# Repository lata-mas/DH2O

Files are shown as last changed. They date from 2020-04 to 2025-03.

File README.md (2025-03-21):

# Dispositivo H2O

Este dispositivo se realizó gracias al apoyo del proyecto UNAM-PAPIIT IT103023.

Este dispositivo se desarrollo con el objetivo de medir la cantidad de agua que se consume en un edificio y poder implementar medidas para evitar consumos excesivos de este valioso recurso.

El dispositivo funciona con un módulo NodeMCU Lolin V3→ESP8266-12E, permitiendo interpretar los datos que recolecta el sensor YF-S201 (sensor de caudal de agua), el microcontrolador  permite interpretar datos y después enviarlos a través de Wifi a una plataforma de imternet. La ventaja más significativa es precisamente esa, que el módulo tiene wifi, permitiendo que pueda enviar datos en tiempo real a diferentes plataformas de visualización, ademas de su reducido tamaño.

A continuación se muestra el esquema general del dispositivo y algunos de sus componetes principales:

1. Sensor de caudal
2. Divisor de voltaje
3. LM324

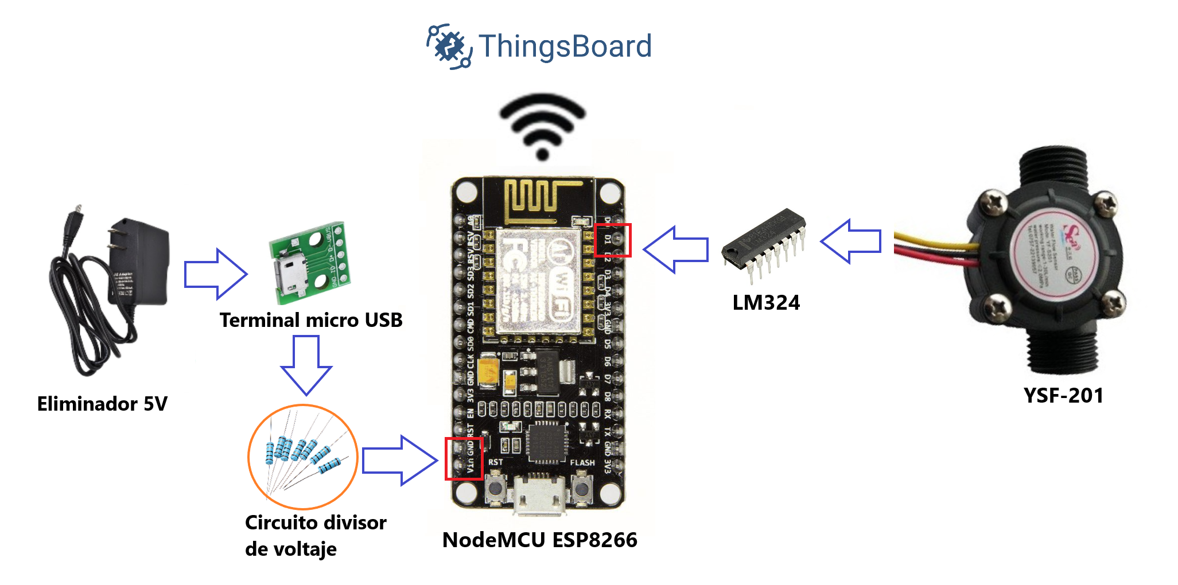
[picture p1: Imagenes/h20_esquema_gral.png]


[Diagrama electrico](https://github.com/Dispositivos-Edificio-Bioclimatico/DH2O/blob/master/Diagramas/DispositivoH2O1Esquem%C3%A1tico.pdf)

## 1. Elementos del repositorio
-  #### En [**docs**](https://github.com/Dispositivos-Edificio-Bioclimatico/DH2O/tree/master/Documentacion) encontramos
	-  Lista de materiales y costos
	-  Manual de operación
	-  Fichas técnicas o datasheet de los módulos, sensores y componentes usados
	- Documento de errores, soluciones y recomendaciones

-  #### En [**diagramas**](https://github.com/Dispositivos-Edificio-Bioclimatico/DH2O/tree/master/Diagramas) encontramos
	- Pictograma de conexión
	- Esquemático de conexión
	
-  #### En [**codigo**](https://github.com/Dispositivos-Edificio-Bioclimatico/DH2O/tree/master/codigo) encontramos
	- Códigos completos
	- Librerías a usar.
	- Explicación.

-  #### En [**Imagenes**](https://github.com/Dispositivos-Edificio-Bioclimatico/Sistema_medicion_apertura_ventanas/tree/main/notebook) encontramos
	-  Imagenes usadas en el repositorio

-  #### En [**carcasa**](https://github.com/Dispositivos-Edificio-Bioclimatico/DH2O/tree/master/Diagramas) encontramos
	-  Planos CAD
	-  Archivos de diseño CAD
	-  Archivos STL para impresión 3D

### 2 Sobre los autores

|Nombre|Instituto/Organización|Email|
| --- | --- | --- |
|Luis Fernando De Olarte Delgado|UTEZ|ferdeod16@gmail.com|
|Marco Antonio Morales Lagunes|UTEZ|marcostony001@gmail.com|
|Julio César Landa López|UTEZ|landajulioc@gmail.com|
|Miguel Ángel Gaspar|ITZ|miguel97gaz@gmail.com|
|Escobar Escobar José Williams|ITE|escobarescobarwilliams@gmail.com|
|Guillermo Barrios del Valle|IER-UNAM|gbv@ier.unam.mx|
|Guillermo Ramírez Zúñiga|IER-UNAM|guraz@ier.unam.mx|
|Giovanni Velazquez Avilez||velazquezgio96@gmail.com|
|José Diego Salgado Nieto||salgadojosediego@gmail.com|

------------

# 3 Alcance

El dispositivo H2O tiene como alcance, en esta etapa, contar con toda la documentación necesaria para ser replicado de manera eficaz y eficientemente, después de ser trabajado por un grupo de personas se espera que el proyecto tenga todo lo que se necesita para que otras personas puedan entender el funcionamiento y requisitos de operación.

------------

### 4 Contacto primario

**Inv. A tiempo completo:** Dr. Guillermo Barrios del Valle

**Email:** gbv@ier.unam.mx

**Posdoc.:** Dr. Guillermo Ramírez Zúñiga

**Email:** guraz@ier.unam.mx

### Colaboradores

**Nombre:** Luis Fernando De Olarte Delgado

**Instituto:** Universidad Tecnológica Emiliano Zapata (UTEZ)

**Email:** ferdeod16@gmail.com

**Nombre:** Marco Antonio Morales Lagunes

**Instituto:** Universidad Tecnológica Emiliano Zapata (UTEZ)

**Email:** marcostony001@gmail.com

**Nombre:** Julio César Landa López

**Instituto:** Universidad Tecnológica Emiliano Zapata (UTEZ)

**Email:** landajulioc@gmail.com

**Nombre:** Miguel Ángel Gaspar

**Instituto:** Instituto Tecnológico de Zacatepec (ITZ)

**Email:** miguel97gaz@gmail.com

**Nombre:** Escobar Escobar José Williams

**Instituto:** Instituto Tecnológico de Ensenada (ITE)

**Email:** escobarescobarwilliams@gmail.com

**Nombre:** Salgado Nieto josé Diego
**Insituto** Universidad Tecnológica Emiliano Zapata (UTEZ)
**Email:** salgadojosediego@gmail.com

#### 5 Seguimiento de actividades del dispositivo H2O

|**Actividad**|**Tiempo estimado de ejecución**|**Referenciación**|
| :---: | :---: | :---: |
|**1. Revisión de documentos existentes necesarios para operarlo de acuerdo a la CHECK-LIST**|2 h|[**°Documentación**](https://github.com/Dispositivos-Edificio-Bioclimatico/SensorH2O/tree/master/Documentacion) |
| | | |
|**2. Verificar si cuenta con los materiales requeridos**|1/2 h|[**Materiales**](https://github.com/Dispositivos-Edificio-Bioclimatico/DH2O/tree/master/Documentacion/Materiales)|
| | | |
|**3. Imprimir la carcasa en 3D (3 PARTES)**|16 h|[**Archivos STL**](https://github.com/Dispositivos-Edificio-Bioclimatico/DH2O/tree/master/carcasa)|
| | | |
|**4. Leer el manual de operación para entender lo que se hará**|1 h|[**Manual**](https://github.com/Dispositivos-Edificio-Bioclimatico/DH2O/blob/master/Documentacion/Manuales/ManualDeOperacion.md)|
| | | |
|**5. Entender los diagramas de conexión**|1/2 h|[**Diagramas**](https://github.com/Dispositivos-Edificio-Bioclimatico/DH2O/blob/master/Diagramas/H2O-Esquem%C3%A1tico_2023ver2-KiCad.pdf)|
| | | |
|**6. Descargar e instalar el código completo (son 5 .py)**|1/2 h|[**Código H2O**](https://github.com/Dispositivos-Edificio-Bioclimatico/DH2O/tree/master/codigo)|
| | | |
|**7. Ejecutar el código como primera prueba y asegurarse que funciona**| | |
| | | |
|**8. Montar el dispositivo en el lugar requerido**|1 h| |
| | | |
|**9. Dejarlo operando durante 24 horas como prueba "Burn it"**|24 h| |
| | | |
|**10. Tiempo total apróximado:**|**3 días**|Dependerá de la habilidad y conocimientos que se tengan, puede llevar menos tiempo o más|

------------

### Thingsboard

Dashboard del dispositivo H2O en la plataforma de Thingsboard:

Miguel_H2O

Las credenciales para tener acceso se deberán solicitar con alguno de los doctores.

La web (Dashboard) se encuentra aquí:

[**Miguel_H2O**](http://iot.ier.unam.mx:8080/dashboard/5825dc60-059e-11eb-9c3f-d1ead9980bc3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)

------------

# 6 Bibliografía

[1] Open Know-How
https://app.standardsrepo.com/MakerNetAlliance/OpenKnowHow/src/branch/master/1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

[2] Github
https://github.com/

[3] EasyEDA
https://easyeda.com/editor

[4] Fritzing
https://fritzing.org/

[5] DILLINGER
https://dillinger.io/

[6] M Editor.md
https://pandao.github.io/editor.md/en.html

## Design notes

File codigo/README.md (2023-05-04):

# SensorH2O
Repositorio para el proyecto de los sensores de flujo de agua para el nuevo edificio del IER-UNAM.

Esta versión del proyecto se conforma de un código modular para facilitar la manipulación de ciertos parámetros que nos ayuden a monitorear el flujo de agua en una tubería o si se requiere hasta 8 tuberías.

En este repositorio se encuentran los codigos requeriods parael funcionamiento del dispositivo.
El mismo se conforma por:

- main.py
- wifi.py
- funciones.py
- funcion.py

A continuación se explicara brevemente el funcionamiento de cada modulo

#### main.py

Este es el principal script de dispositivo y se ejcuta inmediatamente el ESP es alimentado.

Se encarga de declarar las variables las variables necesarias para activar al sensor por medio del llamado a funciones.py
entra en un bucle while y realiza las mediciones, espera 10 segundos a una nueva acción y publica el resultado en Thinsboard.

## funciones.py

**Clase conteo**

Esta clase crea un objeto, este objeto será el sensor que se utilizará para la medición del flujo de agua.

La clase se compone de seis métodos. 

**Método init**

El método **init** no es más que para definir la varibale contador y la variable de entrada pin.

**Método callback**

El método **callback** es el que sirve para aumentar en 1 la variable contador cada señal recibida.

**Método irq**

El método **irq** es el que detecta cada pulso digital y envía la señal al metodo callback.

**Método ecuaciones**

Este método es el que aplica las constantes de conversión al conteo de pulsos digitales para así obtener una variable en Litros.

**Método datos**

Este método tan solo sirve para empaquetar los datos junto con una etiqueta para que estén listos.
para ser publicados en Thingsboard.	

**Método publica**

Este metodo se encarga de verificar si hay algún consumo de agua, de serlo así almacena los datos, en cuanto detecta que ya no lo hay, comineza un conteo, el conteo se interrumpe si vuelve a haber consumo, si el conteo concluye, publica los datos en Thingsboard.

#### wifi.py y funcion.py
Esots archivos son los encargados de realizar la conexión a internet y al servidor de Thingsboard del IER-UNAM

**Última actualización de códigos por José Diego**

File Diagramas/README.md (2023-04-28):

##Diargramas del DH2O

En esta carpeta se presentan los diagramas.

Todo aquel documento qque represente como se construyó el dispositivo, diagramas de conexión, diagramas esequematicos y documentos CAD para su carcasa.
Los diagramas fueron realizados con el software libre KIcad, las carpetas presentan versiones de esquematicos y de pbc que muestran distintas formas de alimentación. Ambas versiones son funcionales, queda a elección del usuario cual usar.

En los directorios es posible encontrr los archivos gerber correspondientes para su  fabricación en PCB.

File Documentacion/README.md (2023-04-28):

## Documentación DH2O

#### En este repositorio es posible encontrar las docuemntación referenten a:

* Lista de materiales y costos
* Manuales de funcionamiento
* Calibración y configuración
* Pendientes identificados
* Recomendaciones

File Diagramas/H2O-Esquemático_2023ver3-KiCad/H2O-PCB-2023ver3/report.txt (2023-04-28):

Plotted to 'C:\Users\bol_j\Desktop\Estadias\DH2O_2\diagramas_ver2023\H2O-Esquemático_2023ver3-KiCad\H2O-PCB-2023ver3\H2O-Esquemático_2023ver3-KiCad-F_Cu.gbr'.
Plotted to 'C:\Users\bol_j\Desktop\Estadias\DH2O_2\diagramas_ver2023\H2O-Esquemático_2023ver3-KiCad\H2O-PCB-2023ver3\H2O-Esquemático_2023ver3-KiCad-B_Cu.gbr'.
Plotted to 'C:\Users\bol_j\Desktop\Estadias\DH2O_2\diagramas_ver2023\H2O-Esquemático_2023ver3-KiCad\H2O-PCB-2023ver3\H2O-Esquemático_2023ver3-KiCad-F_Paste.gbr'.
Plotted to 'C:\Users\bol_j\Desktop\Estadias\DH2O_2\diagramas_ver2023\H2O-Esquemático_2023ver3-KiCad\H2O-PCB-2023ver3\H2O-Esquemático_2023ver3-KiCad-B_Paste.gbr'.
Plotted to 'C:\Users\bol_j\Desktop\Estadias\DH2O_2\diagramas_ver2023\H2O-Esquemático_2023ver3-KiCad\H2O-PCB-2023ver3\H2O-Esquemático_2023ver3-KiCad-F_Silkscreen.gbr'.
Plotted to 'C:\Users\bol_j\Desktop\Estadias\DH2O_2\diagramas_ver2023\H2O-Esquemático_2023ver3-KiCad\H2O-PCB-2023ver3\H2O-Esquemático_2023ver3-KiCad-B_Silkscreen.gbr'.
Plotted to 'C:\Users\bol_j\Desktop\Estadias\DH2O_2\diagramas_ver2023\H2O-Esquemático_2023ver3-KiCad\H2O-PCB-2023ver3\H2O-Esquemático_2023ver3-KiCad-F_Mask.gbr'.
Plotted to 'C:\Users\bol_j\Desktop\Estadias\DH2O_2\diagramas_ver2023\H2O-Esquemático_2023ver3-KiCad\H2O-PCB-2023ver3\H2O-Esquemático_2023ver3-KiCad-B_Mask.gbr'.
Plotted to 'C:\Users\bol_j\Desktop\Estadias\DH2O_2\diagramas_ver2023\H2O-Esquemático_2023ver3-KiCad\H2O-PCB-2023ver3\H2O-Esquemático_2023ver3-KiCad-Edge_Cuts.gbr'.
Archivo de trabajo Gerber 'C:\Users\bol_j\Desktop\Estadias\DH2O_2\diagramas_ver2023\H2O-Esquemático_2023ver3-KiCad\H2O-PCB-2023ver3\H2O-Esquemático_2023ver3-KiCad-job.gbrjob' creado.
Info: Listo.

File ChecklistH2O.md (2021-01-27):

# CHECKLIST H2O
|Archivo/doc|Pendientes |Observación1|Observación2|Status |
| --- | --- | --- | --- | --- |
|Lista de costos|0|Unitario y total| |Listo|
|SRC completos|0| |Lo de Miguel|Listo|
|Pictogramas|0|De 1,2 y 8 sensores| |Listo|
|Esquemático|0| |1 y 8 sensores EasyEDA|Listo|
|Diseño PCB|0| |8 sensores EasyEDA|Listo|
|Gerber PCB|0|De 8 sensores| |Listo|
|Lista materiales|0|De 1 y 8 sensores| |Listo|
|Planos CAD|0|Planos en PDF| |Falta|
|CAD|1|En SolidWORKS|Falta FreCAD|Listo|
|STL|0| | |Listo|
|Manual Operación|0| | |Listo|
|Manual Ensamble|0| | |Listo|
|Fichas Técnicas|0| | |Listo|
|Doc. Errores y soluciones|0| | |Listo|

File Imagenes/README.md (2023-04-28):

## Imagenes

En este repositirio se encuentran alojadas todas las imagenes que se usan en el repositirio del DH2O

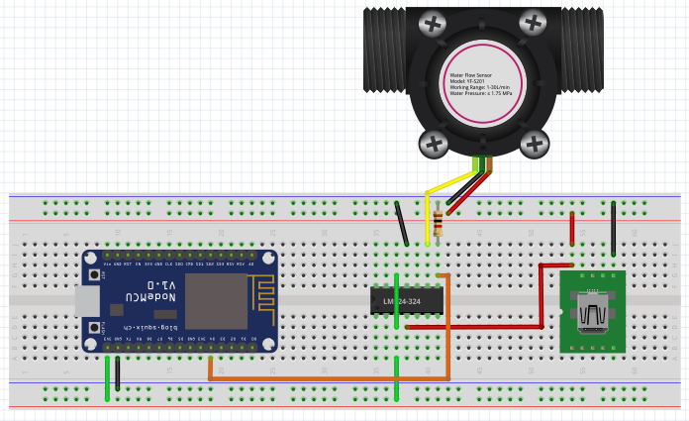
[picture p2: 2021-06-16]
Diagramas/FRITZINGH201.PNG

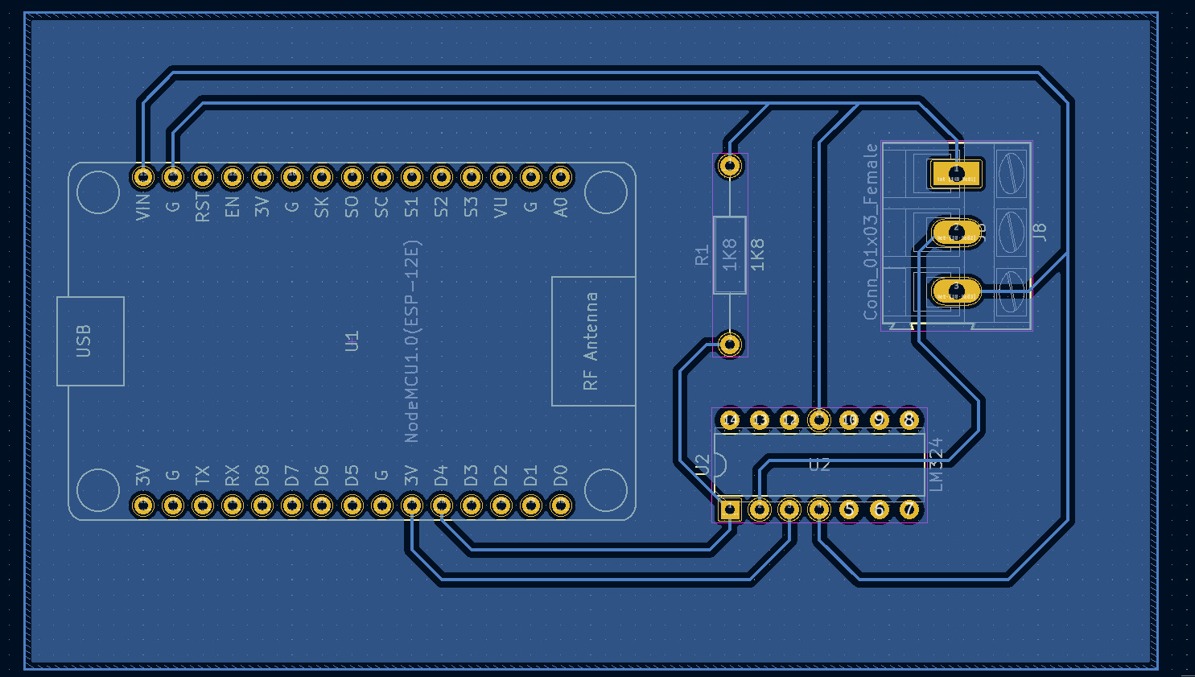
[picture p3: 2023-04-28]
Diagramas/DH2O_pcb_v2.png

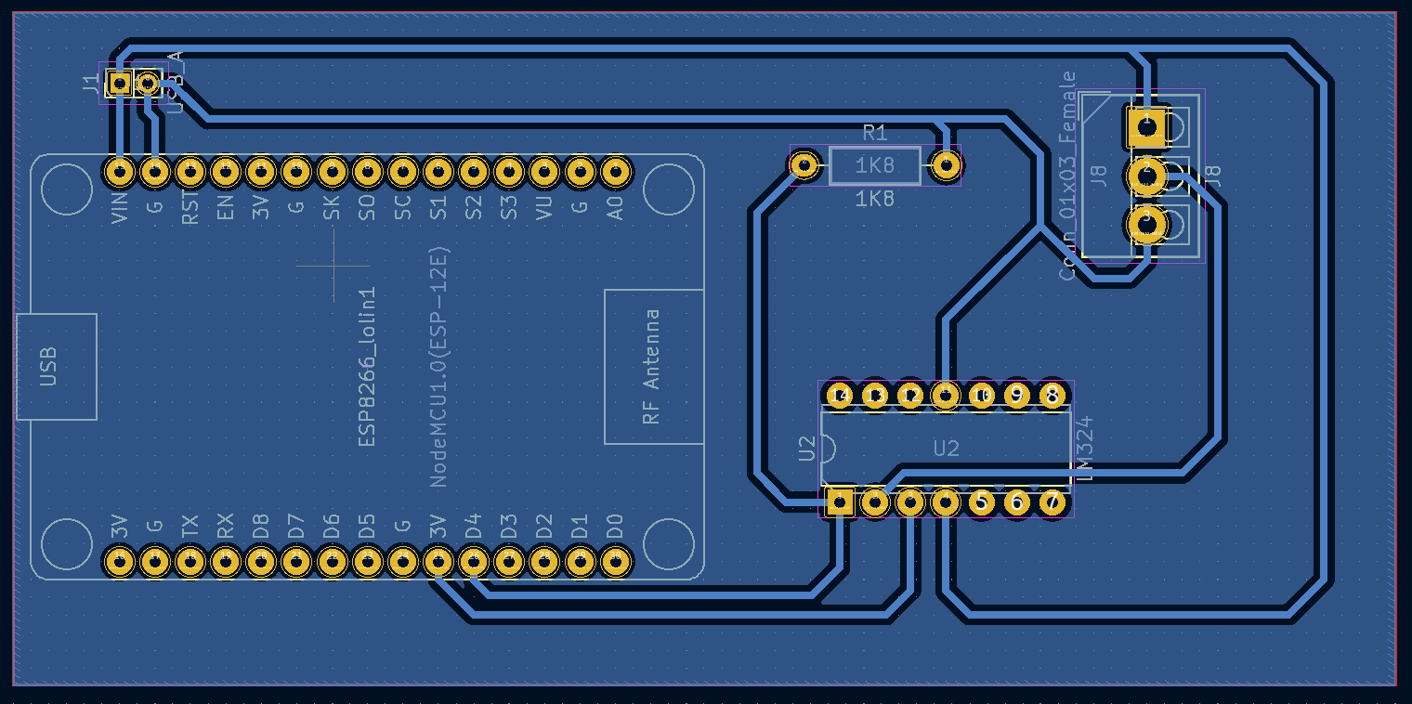
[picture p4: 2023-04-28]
Diagramas/DH2O_pcb_v3.png

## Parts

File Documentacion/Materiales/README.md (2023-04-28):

# Lista de materiales del Dispositivo H2O1
###### Esta lista es sólo para componentes de la placa
#### Título del diseño:|Dispositivo H2O1|

En este repositiro se encuentran los matreiales, sus costos y sus hojas de datos.

A continuación se presentará la lista de materiales general del DH2O y sus costos

|  Cantidad | Referencias | Valor | Código almacén | Coste Unitario  |
| --- | --- | --- | --- | --- |
|*1 Integrados*| U1-U2  |LM324 | |$12.00 |
|**Subtotal**| | | | **$12.00** |
|*1 Resistencia*| R1 | 1KΩ | W1K | $1.50 |
|*3 Resistencias*| R9-R10-R13 | 2 KΩ | W1K | $2.50 |
|*3 Resistencias*| R11-R12-R14 | 220Ω | W1K | $1.50 |
| **Subtotal**  | | | |**$13.50**|
|*1 TBLOCK-M3*|J1-J8|| | $4.65  |
|*1 USBCONN*|J9| | |$15.73|
|*1 NodeMCU3*|NMCU2| | |$150.00|
|*1 YF-S201*|S1-S8| | |$130.00|
|**Subtotal**|| | |**$300.38**|
|**Total**|| | |**$325.88**|

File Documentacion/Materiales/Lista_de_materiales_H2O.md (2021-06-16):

#Lista de materiales del dispositivo H2O
###### Lista sólo para los componentes de la placa
#### Fecha del diseño: Viernes 25 de Septiembre del 2020
#### Última modificación del diseño: Domingo 13 de Diciembre del 2020
|Cantidad|Referencias|Valor|Código almacén|
| --- | --- | --- | --- |
|1 Integrados|U1-U2|LM324||
|1 Resistencias|R1|1KΩ|W1K|
|3 Resistencias|R9-R10-R13|2KΩ|W1K|
|3 Resistencias|R11-R12-R14|220Ω|W1K|
|1|J1-J8|TBLOCK-M3||
|1|J9|USBCONN||
|1|NMCU2|NODEMCU V3||
|1|S1-S8|YF-S201|

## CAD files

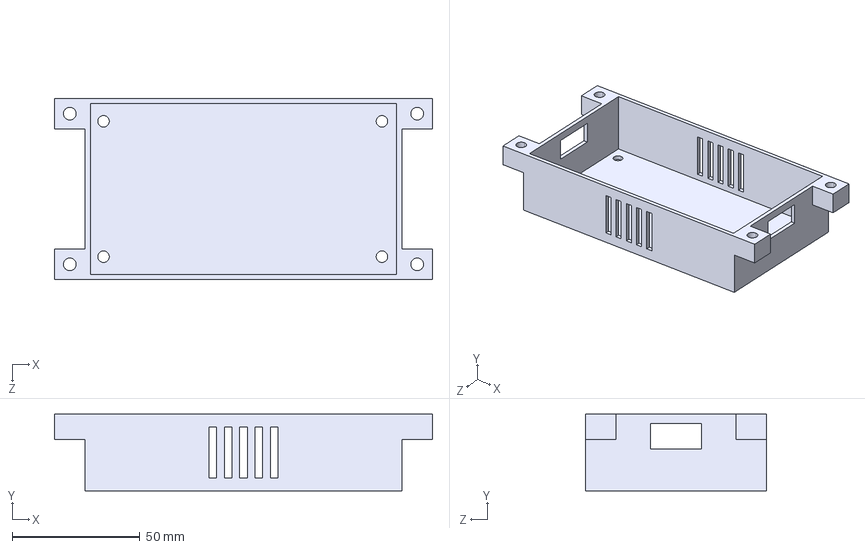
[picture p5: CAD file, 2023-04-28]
carcasa/baseDH2O.STEP
148.0 x 30.0 x 71.0 mm

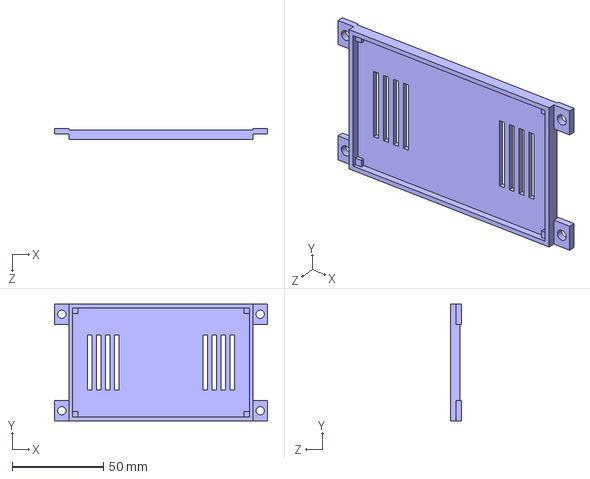
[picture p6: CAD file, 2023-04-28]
carcasa/baseplaca_ver1.STEP
117.0 x 64.0 x 5.80 mm

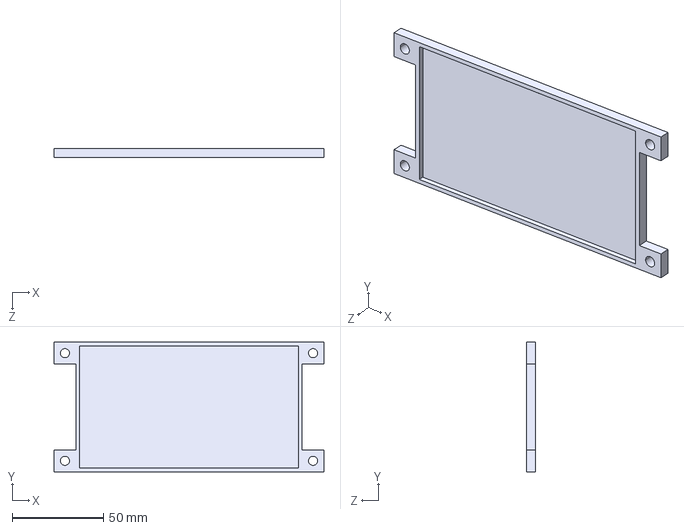
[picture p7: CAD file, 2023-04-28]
carcasa/tapaDH2O.STEP
148.0 x 71.0 x 5.00 mm

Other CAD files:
carcasa/baseDH2O.STL
carcasa/baseplaca_ver1.STL
carcasa/tapaDH2O.STL

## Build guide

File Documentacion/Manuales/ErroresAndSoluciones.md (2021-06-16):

## Errores, soluciones y recomendaciones para operar el dispositivo H2O



1.	Del repositorio del dispositivo de agua para evitar que el ESP no cargue el boot.py por defecto y evitar confusión al momento de cargar los archivos, se recomienda cambiar el nombre de ese mismo documento boot.py a uno que se nos haga cómodo identificar, así evitamos confusión de cargar el boot.py que no es.

2.	El sensor de flujo deberá trabajarse de forma horizontal y no vertical, lo anterior es porque de manera vertical el líquido del fluido puede aumentar la presión y la velocidad por la gravedad, por lo que puede existir variaciones al leer datos.



3.	Considerar que no es un sensor de precisión por lo que la orientación, presión del agua y otras condiciones pueden afectar la medición.

4.	Se recomienda calibrar el sensor realizando mediciones con volúmenes conocidos. Calibrado puede llegar a tener una precisión de hasta 10%.

	El repositorio que está en la plataforma de GitHub, aunque cuenta con lo necesario para que el prototipo de medición de flujo de agua funcione, puede someterse a algunas mejoras.

5.	Considerar que la imagen de arriba es sólo para prueba, realmente no debe ponerse a esas distancias en cuanto a los codos se refiere, porque hay pérdidas de presión y velocidad que termina por afectar el flujo, de preferencia que sea a 30cm de distancia de cualquier accesorio.

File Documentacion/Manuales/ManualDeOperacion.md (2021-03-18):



## Universidad Nacional Autónoma de México
### Instituto de Energías Renovables
### Manual de operación
## Dispositivo medidor de caudal (H2O)

------------

#### Tabla de contenido

1. Resumen ................................................................................................................................................. 3
2. Sensor de caudal ................................................................................................................................. 3
3. Descripción general del Hardware ............................................................................................... 4
4. Objetivo general del dispositivo ................................................................................................... 4
5. Esquema general del dispositivo de prueba y principio de funcionamiento............... 5
6. Descripción a detalle de cada parte y componente del dispositivo ............................... 6

	6.1 NodeMCU Lolin V3 ESP8266-12E ......................................................................................... 6
	
	6.2 Características de la placa NodeMCU V3 Lolin ................................................................ 7
	
	6.3 Los terminales del NodeMCU V3 Lolin ................................................................................ 7
	
	6.4 ¿Qué quiere decir esto? ¿Cómo lo puedo interpretar? ................................................. 8
	
	6.5 Detalles del NodeMCU ............................................................................................................... 9
7. Identificación de Pines ..................................................................................................................... 10

	7.1 Patillaje de la tarjeta NodeMCU V3 Lolin ........................................................................... 10
	
	7.2 Patillaje del ESP8266-12E ......................................................................................................... 10
	
	7.3 Los LED´s azules ........................................................................................................................... 11
8. Instalación de Python en Linux ..................................................................................................... 12
9. Configuración del ESP8266-12E ................................................................................................... 12
10. Cargar los códigos del dispositivo H2O .................................................................................... 17
11. Agregar un dispositivo en Thingsboard .................................................................................... 18
12. Calibrar el sensor ................................................................................................................................ 20

------------

**1. Resumen**

En el Instituto de Energías Renovables de la UNAM en Temixco Morelos, se tiene planeado construir un edificio sustentable, por lo que hay variables que tendrán que ser medidas y ser compatibles con el medio ambiente, para esto se tiene contemplado la construcción de dispositivos electrónicos que ayuden a medir dichas variables como: agua, consumo eléctrico, temperatura, luminosidad de espacios, nivel sonoro entre otras, con la intención de poder manipular los datos para posteriormente tener control sobre ellas y lograr el confort de los usuarios.
Cabe mencionar que un edificio sustentable debe cumplir con ciertas normas para que pueda ser considerado como sustentable, es por eso la necesidad de controlar dichas variables.

**2. Sensor de caudal**

Los sensores de caudal recogen las velocidades del flujo de aire o líquidos. Los sensores de caudal usan diferentes principios de medición. Este sensor se acopla muy bien a la tubería de agua de cualquier edificio o casa y contiene un sensor de molino para medir la cantidad de líquido que ha pasado a través de él. También tiene un sensor magnético de efecto Hall que emite un impulso eléctrico con cada revolución. El sensor de efecto Hall está sellado para permanecer seguro y seco.
El sensor viene con tres cables:
Rojo (energía 5-24 VDC)
Negro (tierra)
Amarillo (salida de pulsos de efecto Hall)
Al contar los pulsos de la salida del sensor, se puede calcular fácilmente el flujo de agua. Cada pulso es de aproximadamente 2.25 mililitros. Cabe mencionar que el sensor YF-S201, no es un sensor de precisión, y la frecuencia del pulso varía un poco dependiendo de la velocidad de flujo, presión del flujo y la orientación del sensor. Si se necesita más del 10% de precisión se tendrá que hacer la calibración adecuada.
La señal de pulso es una simple onda cuadrada así que es bastante fácil de registrar y convertir en litros por minuto utilizando la siguiente ecuación.



*Pág. 3*

------------

**3. Descripción general del hardware**

El dispositivo está conformado por un módulo NodeMCU que se encarga de adquirir datos que envía el sensor de caudal y posteriormente envía información a Thingsboard para visualizar los datos de manera gráfica en tiempo real, para posteriormente poder decidir si es necesario reducir el consumo y controlarlo como sea conveniente.

**4. Objetivo general del dispositivo**

Este dispositivo se elaboró con la intención de medir la cantidad de agua que se consume en un edificio y poder implementar medidas para evitar consumos excesivos de este valioso recurso.

*Pág. 4*

------------

**5. Esquema general del dispositivo de prueba y principio de funcionamiento**

El dispositivo funciona con un módulo NodeMCU Lolin V3→ESP8266-12E, permitiendo interpretar los datos que recolecta el sensor YF-S201, el módulo tiene un microcontrolador que permite interpretar datos y después enviarlos a través de Wifi. La ventaja más significativa es precisamente esa, que el módulo tiene wifi, permitiendo que pueda enviar datos en tiempo real a diferentes plataformas de visualización, otra ventaja es su tamaño.



**Representación del esquema armado para prueba**

El esquema presentado arriba, se realizó con la intención, de poder visualizar de manera muy general una forma de hacer pruebas para calibrar el sensor antes de ser implementado en alguna de las instalaciones eléctricas, si se desea una vez cargado el código al ESP alimentar al mismo con una fuente externa o con la misma entrada del USB, será necesario hacer el arreglo de resistencias (divisor de voltaje).

*Pág. 5*

------------

**6. Descripción a detalle de cada parte y componente del dispositivo**

**6.1 NodeMCU Lolin V3 ESP8266-12E**

El NodeMCU es un módulo que tiene el ESP8266, además ya tiene conexión directa mediante el chip CH340 a USB, tiene wifi y muchas terminales.
El NodeMCU es en realidad un ESP8266-12 con conector a USB (CH340 driver), es mejor que el ESP8266 porque éste tiene más complicación al conectar y configurar ya que no tiene conector USB. Además, el pequeño ESP8266-1 solo tiene dos puertos de conexión y el NodeMCU al contener al ESP8266 tiene 16 puertos de conexión.
Existen 3 versiones:
El ESP8266-1, tiene un precio aproximado de $25.00 pesos mexicanos en el mercado chino. Solo tiene 2 puertos de entrada/salida. Es complicado de conectar al ordenador, hace falta un FTDI o un Arduino para conectarlo al ordenador, sus pines de conexión no entran bien en la placa de pruebas.
El ESP8266-12E, es una versión del anterior, pero con 16 puertos de entrada/salida. También tiene el mismo problema de conexión al ordenador para programarlo, ya que no tiene conector USB. Su precio aproximado es de $25.00 pesos mexicanos en el mercado chino. Los pines machos para el conector suelen venir con el pedido, pero hay que soldarlo.
El NodeMCU V3 Lolin, tiene un precio de unos $75.00 pesos mexicanos en el mercado chino. Es una tarjeta (3x6 cm) que, tiene integrado el ESP8266, con lo cual tiene 16 puertos de entrada/salida. Además, la gran ventaja es que tiene el chip CH340 que sirve para conectarlo al ordenador por USB. Tiene conectores machos que se pueden insertar en la placa de pruebas, pero es un poco ancho y no deja espacio en los pines laterales de la placa de pruebas. Velocidad de 80 MHz.



*Pág. 6*

------------

**6.2 Características de la placa NodeMCU V3 Lolin**



**6.3 Los terminales del NodeMCU V3 Lolin**

Esto es muy importante poder identificar los terminales y puede resultar hasta confuso y tedioso de lograr cuando aún se está empezando con la placa.
La nomenclatura de terminales del NodeMCU son diferentes de los GPIO´s y hasta en el código al momento de declararlos.
Los terminales de la tarjeta NodeMCU se denominan: D0, D1, D2, D3, D4, D5, D6, D7, D8(RX), D9(TX), D10, SD2 y SD3.
Los terminales del integrado ESP8266-12E, que está soldado a la tarjeta se denominan: GPIO0, GPIO1, GPIO2, GPIO3, GPIO,4, GPIO5, GPIO6, GPIO7, GPIO8, GPIO9, GPIO10, GPIO11, GPIO12 y GPIO13.
Esto es confuso, porque resulta que no coinciden, es decir el D7 no es el GPIO7, esta es la confusión principal de casi todas las fuentes de información, dando por hecho que todos saben que no se identifica con los mismos números.
A continuación, se presenta una tabla donde se relacionan las terminales de la tarjeta con los del ESP8266, para poder identificar de manera fácil cada uno.

*Pág. 7*

------------



**6.4 ¿Qué quiere decir esto? ¿Cómo lo puedo interpretar?**

Supongamos que conectamos un LED al terminal D1 de la tarjeta NodeMCU, como en la imagen.



El terminal D1 de la tarjeta corresponde con el GPIO5, según la tabla presentada anteriormente.
En el código se debe poner el número 5, es decir el GPIO5. No debe confundirse con el número de terminal de la tarjeta.
Esto es demasiado confuso cuando realmente no se conoce nada de la tarjeta y seguirá causando confusión hasta que se tenga claro cómo se identifica.

*Pág. 8*

------------

**6.5 Detalles del NodeMCU**



Se puede observar el LED azul integrado en la placa del ESP8266-12E.
La frecuencia del Wifi es de 2,4 GHz, es decir, longitud de onda→ λ= velocidad de la luz/frecuencia= 300,000,000/2,400,000,000=12,5cm
Las ondas emitidas tienen una longitud de 12,5 cm, por eso se llama microondas.
Potencia de 25 dBm, son decibelios referenciados a miliwatios, para convertirlos en watios, 10^2(25/10) * 10^ (-3) = 0,32 W es la potencia de emisión.
El CHIP 340, el conector micro USB, un cristal de 12 MHz.
Un regulador de tensión que cambia los 5V del USB a los 3,3 V que necesita el ESP8266.
También se observa dos pulsadores, uno FLASH y otro RST.
Algunas resistencias de superficie SMD, por ejemplo, la de 103 sería de 10,000 Ohmios, la 471, sería de 470 Ohmios.

*Pág. 9*

------------

**7. Identificación de pines**

**7.1 Patillaje de la tarjeta NodeMCU V3 Lolin**



**7.2 Patillaje del ESP8266-12E**



**7.3 Los LED´s azules**

Se debe considerar que se dispone de dos LED azules.
Uno en el ESP8266-12E, correspondiente a su GPIO2 (que debe ir al terminal D4 del NodeMCU).
Otro en la misma tarjeta del NodeMCU, correspondiente al GPIO16 (que irá al terminal D0 del NodeMCU).



*Pág. 11*

------------

**8. Instalación de Python en Linux**

1. Se debe actualizar los paquetes con el comando “sudo apt update” abriendo la terminal en Linux.



Posteriormente se debe instalar Python, de igual forma usando la terminal, es preferible instalar Python de versiones mayores que la de 3.0 porque con versiones inferiores es probable que algunas librerías presenten problemas al momento de usarlas.

2. El comando para instalar Python es “sudo apt install python3".



Después se debe instalar el administrador de paquetes para Python (Pip3), que nos ayuda a agregar librerías o paquetes de Python.

3. El comando a utilizar es “sudo apt install Python3-pip”.



Los pasos que deben hacerse previamente a todo el proceso mostrado a continuación se encuentran en la pág.

[http://docs.micropython.org/en/latest/esp8266/tutorial/intro.html#deploying-the-firmware](http://docs.micropython.org/en/latest/esp8266/tutorial/intro.html#deploying-the-firmware)

De igual forma ahí se encuentran los firmwares que pueden ser usados según el ESP con el que se vaya a trabajar.

**9. Configuración del ESP8266-12E**

Como primer paso a seguir antes de meterse a lo que es el sensor de caudal

1. Descargar de la página siguiente:

[https://micropython.org/download/esp8266/](https://micropython.org/download/esp8266/)

el firmware a utilizar, según la capacidad del ESP8266-12E, para este caso en particular, el que se usará es:



ese firmware descargado se guardará en una carpeta previamente creada por nosotros en alguna parte de nuestro equipo con algún nombre en específico.

*Pág. 12*

------------

Asumiendo que ya se ha guardado el firmware descargado en una carpeta en el equipo.

2. Del mismo link anteriormente mencionado, entrar a la parte de la página en donde se muestran las letras rojas “in the tutorial”.



Una vez dentro del link, están los pasos para poder “limpiar” o “formatear” el ESP, para posteriormente cargar el firmware y se logre un buen funcionamiento.

3. Se deberá conectar el ESP8266-12E a nuestro equipo para realizar los siguientes pasos.

4. Como cuarto paso para llevar a cabo lo anterior es abrir la terminal del sistema operativo Linux, una vez abierto, se deberá copiar lo siguiente:



En caso de no poder usar ese comando, se puede sustituir con: "sudo apt install esptool"

El comando anterior permite cargar herramientas que proporcionan acceso a muchas de las funciones de señal.

5. Para conocer en qué puerto está conectado nuestro ESP debemos escribir el siguiente comando en la terminal.

**ls /dev/tty***



Lo anterior es para conocer exactamente en qué puerto está conectado nuestro ESP, dependiendo del puerto nos aparecerá USB0 o USB1.

A continuación, se debe formatear (borrar flash) de la tarjeta que se está usando, en este caso el ESP8266, si sucede cualquier detalle cuando ya se está operando con la tarjeta ESP es necesario empezar nuevamente desde este paso para garantizar que la tarjeta se está “limpiando” de todos los programas que tiene cargado.

*Pág. 13*

------------

Para formatear la tarjeta completamente es necesario tener conectado el ESP y se utiliza el comando “esptool.py -port /dev/ttyUSB0 erase_flash".

6. El siguiente paso, es copiar en la terminal el comando:





**NOTA:** En ocasiones se presenta un detalle de error despuès de ejecutar el comando el comando anterior, esto sucede porque en algunas placas genèricas es
          necesario entrar al modo "FLASH", lo anterior se logra de la siguiente manera:
	  
	Paso 1: Escribir en la terminal el comando para flashear la tarjeta, el comando mostrado arriba pero sin ejecutarlo.
	
	Paso 2: Sin ejecutar el comando, se debe desconectar el cable de datos del ESP.
	
	Paso 3: Presionar el botòn del ESP llamado "FLASH", mantener presionado.
	
	Paso 4: Sin dejar de presionar, se deberà conectar el cable de datos al ESP, presionando en todo momento.
	
	Paso 5: Aùn presionando el botòn y el cable conectado, debera`ejecutar la lìnea de comando previamente preparada en la terminal, en cuanto ejecute el 
		comando debe dejar de presionar el botòn y si realizò bien el procedimiento no habrà error y se llevarà a cabo el proceso satisfactoriamente.
	
Lo anterior es para “limpiar” el esp8266, posterior a eso, se procede a abrir la terminal de nuestro equipo y se deberá tener conectado el ESP8266 al equipo.

7. Se deberá escribir en la terminal lo siguiente:



**cd** es para meternos al disco de nuestro equipo
**ls** es para poner en forma de lista lo que tenemos en nuestro equipo
En este caso en particular, en la carpeta “firmwares” que se creó previamente se descargó y se guardó el firmware a utilizar.

8. Debemos acceder a ella de la siguiente manera:

**cd firmwares/**
Una vez dentro, escribimos nuevamente
**ls** para enlistar lo que hay dentro de la carpeta
Lo único que tenemos dentro de esa carpeta es el firmware a utilizar que previamente se ha descargado.
Conectado el ESP, se procede con la instalación del firmware a utilizar de la siguiente forma:
“esptool.py –port/dev/ttyUSB0 --baud 46080 write_flash_size=detect 0 (aquí va el firmware)”.

9. Para este caso en particular todo el comando con el firmware descargado previamente quedaría así:

“esptool.py –port/dev/ttyUSB0 --baud 46080 write_flash_size=detect 0 esp8266-20200911-v1.13.bin



*Pág. 14*

------------

Puede suceder que el comando no funcione correctamente a la primera, si es así, se tendrá que implementar el siguiente comando:
“esptool.py --port dev/ttyUSB0 –baud 46080 write_flash –flash_size=detect -fm dio 0 esp8266-20200911-v1.13.bin”
Hasta este punto si los comandos se ejecutaron sin presentar ningún error, Micropython debería estar instalado en el ESP.

10. Ahora es necesario instalar el intérprete mpfshell con el comando “sudo pip install mpfshell” o con el comando “sudo pip3 install mpfshell”.



11. Escribir el comando “mpfshell”.



12. Con el comando “open ttyUSB0” u “open ttyUSB1” se conecta el ESP para cargar códigos.



13. Después listamos con (ls) y obtenemos el archivo que el ESP carga por defecto cada vez que abrimos la tarjeta (boot.py).



El otro archivo que el ESP ejecutará por defecto es el “main.py”, para eso se deberá crear antes.
Se deberá guardar de preferencia en el mismo lugar (directorio), en el que se obtuvo el “boot.py” con la intención de que al momento de ejecutar nuevamente el comando “open ttyUSB0”, se encuentre en el mismo directorio y no se tenga que abrir de manera individual.

14. Abrir un lector de texto y crear el archivo “main.py”, para obtener finalmente los dos ejecutables.



*Pág. 15*

------------

Como demostración, los dos archivos se guardaron en el directorio “Desktop”, internamente en el directorio “Prueba” y se ha creado unas líneas de código en el archivo main.py para una prueba.
El ESP debe estar conectado al equipo en todo momento para después solo cargar los archivos.

15. Abrimos la terminal y nos vamos directamente a donde se guardaron los 2 archivos, los abrimos con el comando “gedit main.py” y “gedit boot.py”, no es necesario abrir el segundo archivo.

16. Escribimos las líneas de código en el archivo main.py (print “Hola mundo”), guardamos y cargamos al ESP, nos conectamos ejecutando mpfshell y cargamos una vez que se ha conectado con el comando “put boot.py” y “put main.py”.

17. Ejecutamos el comando “repl” y después “ctrl D” para correr el programa y visualizamos la línea de código que hemos escrito.



En este caso, el programa se detiene sólo porque es una línea de código sin una condición cíclica, pero en caso de que el programa cargado al ESP sea cíclico, deberá detenerse presionando “ctrl C” y para cerrar el entorno se presiona “ctrl +”.

*Pág. 16*

------------

**10. Cargar los códigos del dispositivo H2O**

Para el siguiente proceso, es necesario ir a la plataforma donde se encuentran los códigos para el funcionamiento del dispositivo H2O.
Se deberá descargar todos los archivos en el equipo y guardar en un directorio, con ayuda del pictograma del dispositivo H2O, se realizan las conexiones necesarias, identificando los GPIO adecuados para el sensor y modificando en el código, en caso de tener dudas con la identificación de pines, en la Tabla 2 se encuentra la descripción de pines del módulo con el ESP8266.
Cuando ya se ha identificado el Pin a utilizar con la entrada del sensor, se procede a cargar los programas.
En el archivo main.py se deberá cambiar el Pin de entrada, en el que el sensor será conectado.
En el archivo funciones.py se deberá introducir el nombre de la red local de wifi y la clave o contraseña de la red. En este paso, por lo pronto será todo lo que se tiene que modificar de los códigos.



*Pág. 17*

------------

**11. Agregar un dispositivo en Thingsboard**

Ir a la página oficial de Thingsboard, se puede usar los datos de versión demo o registrarse con datos personales y entrar para crear un nuevo espacio para publicar.

1. Dirigirse dentro de la página a la sección de dispositivos.



2. Buscar en alguna parte de la pantalla el signo +, para agregar un nuevo dispositivo, ya que la página cambia en ocasiones debido a actualizaciones se encuentra en el mismo lugar.



3. Introducimos el nombre deseado y agregamos.



*Pág. 18*

------------

4. Ya que se ha creado el espacio, podemos seleccionar nuestro nuevo dispositivo para ver los detalles y copiamos el ID y el token para después pegarlo en nuestro código.



5. En el archivo funciones.py se deberá pegar el ID y token que hemos copiado anteriormente.



6. Posterior a eso, en la parte de “última telemetría” se podrá visualizar los datos que se ha estado enviando.



*Pág. 19*

------------

**12. Calibrar el sensor**

Cuando ya se ha realizado todo lo anterior sin ningún problema, se procede a cargar los códigos modificados al ESP y se ejecuta en la terminal para visualizar que en realidad está midiendo y enviando datos el sensor. Para poder calibrar el sensor, es necesario tener 1 recipiente con agua de una medida establecida, puede ser de 1L,2L,3L, según con lo que se disponga.
En el archivo main.py se encuentra el valor de K, es la constante que se tiene que ir modificando, hasta que el código completo, funcionando, mida 1L cuando se le desocupe 1L y después corroborar con otras cantidades.





*Pág. 20*

------------



Para el ciclo de prueba 4, se podía ver que en comparación al 3, ya se estaba pasando con los valores de prueba, es decir, del ciclo 3 medir 1.0078L al ciclo 4 medir 1.0073L, en los valores promedio estaba disminuyendo y acercándose a 1L en ambos casos, pero si nos guiamos en los valores individuales de los ciclos de prueba, se puede ver que hay más valores en el ciclo 4, por debajo de 1L, por eso se determinó que el valor de K debería estar más cercano al del ciclo 3.



Finalmente, en el archivo main.py se dejó con el valor de K a 0.0017380.



*Pág. 21*

------------

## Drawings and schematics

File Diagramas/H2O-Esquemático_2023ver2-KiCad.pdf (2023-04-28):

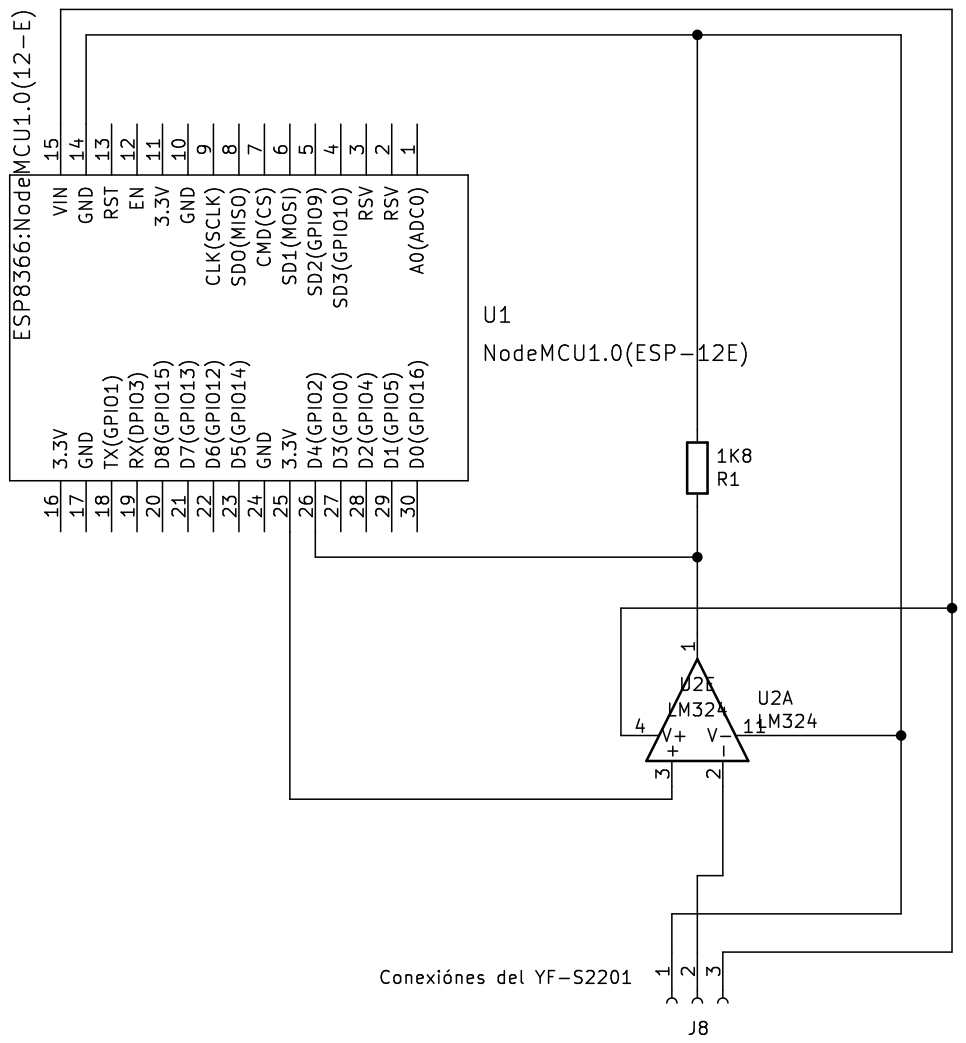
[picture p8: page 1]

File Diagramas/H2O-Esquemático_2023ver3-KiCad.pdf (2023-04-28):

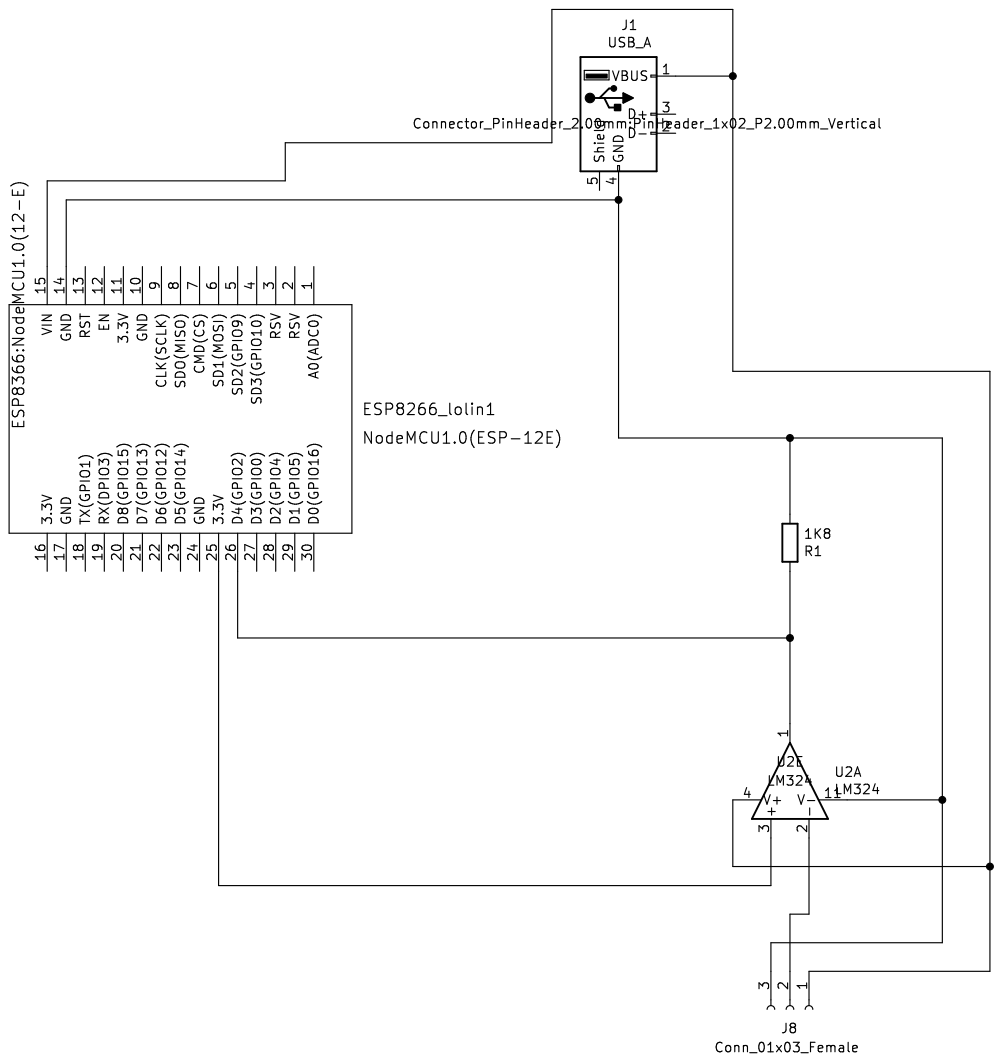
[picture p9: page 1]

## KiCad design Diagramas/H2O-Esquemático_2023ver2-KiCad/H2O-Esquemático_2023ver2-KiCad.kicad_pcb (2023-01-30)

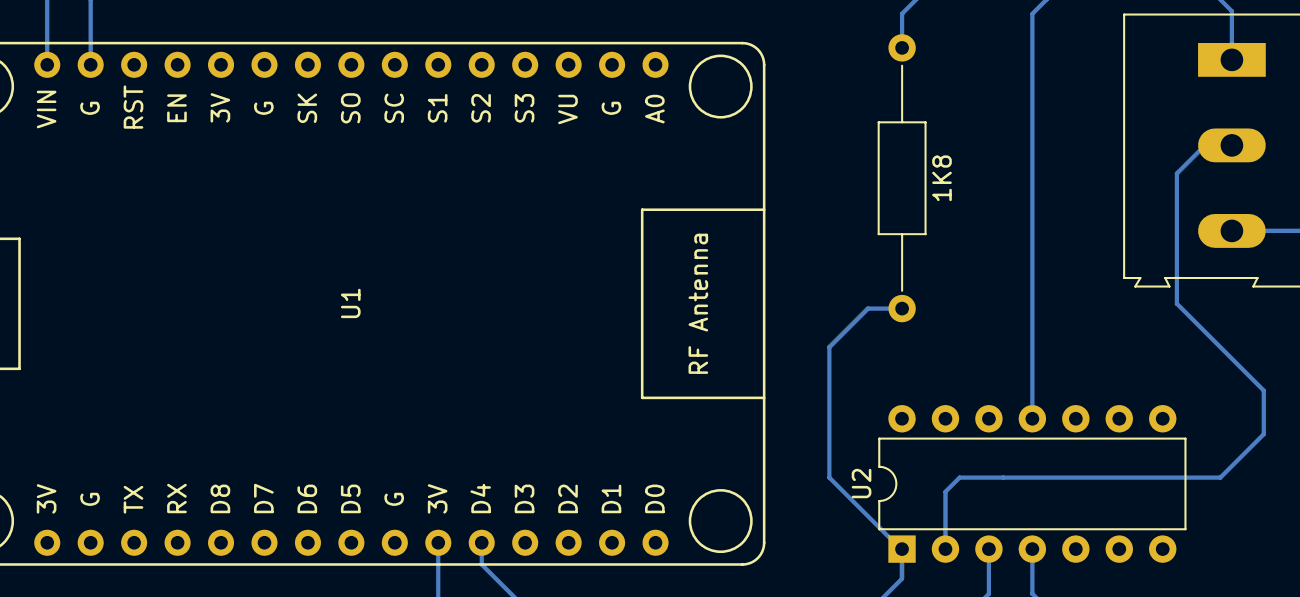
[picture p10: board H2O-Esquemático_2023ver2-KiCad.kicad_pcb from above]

Board: 2 copper layers, 4 parts (0 on the bottom side), 5 nets.

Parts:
1K8: R1; R_Axial_DIN0207_L6.3mm_D2.5mm_P15.24mm_Horizontal
J8: Conn_01x03_Female; TerminalBlock_Altech_AK300-3_P5.00mm
U1: NodeMCU1.0(ESP-12E); NodeMCU1.0(12-E)
U2: LM324; DIP-14_W7.62mm

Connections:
unnamed: 1K8.1, J8.1, U1.14 (GND), U2.11 (V-)
unnamed: 1K8.2, U1.26 (D4(GPIO2)), U2.1
unnamed: J8.2, U2.2 (-)
unnamed: J8.3, U1.15 (VIN), U2.4 (V+)
unnamed: U1.25 (3.3V), U2.3 (+)

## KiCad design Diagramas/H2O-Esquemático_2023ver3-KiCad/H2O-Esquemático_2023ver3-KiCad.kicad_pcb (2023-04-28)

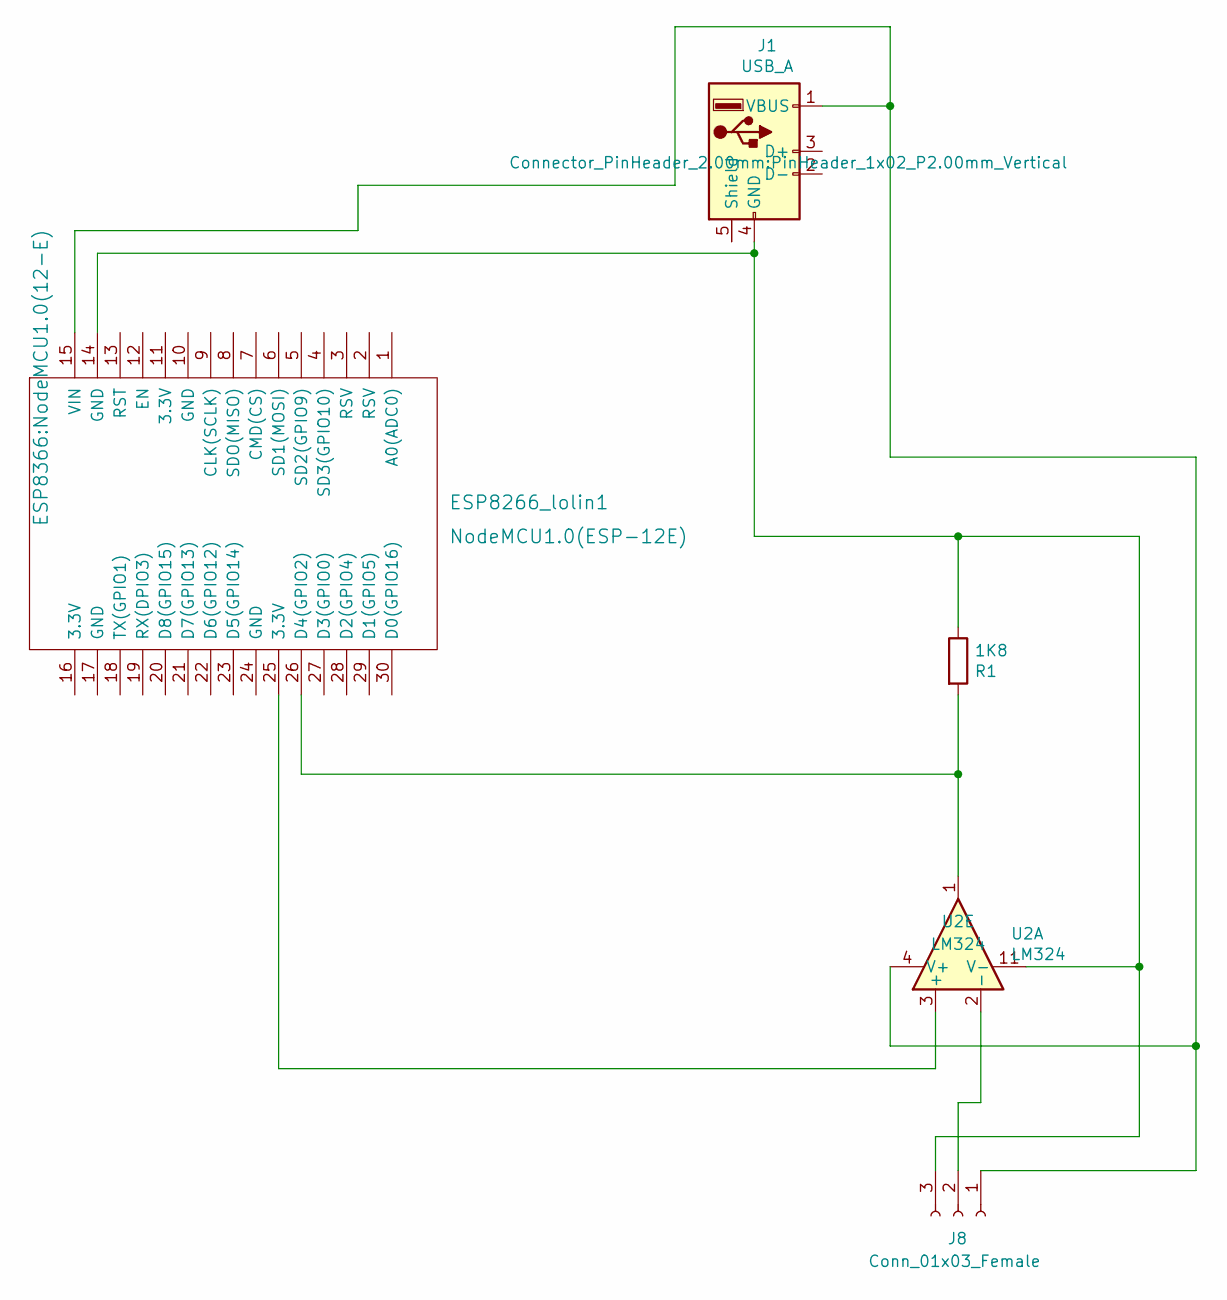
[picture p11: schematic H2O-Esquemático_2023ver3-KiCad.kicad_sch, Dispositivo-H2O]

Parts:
1K8: R1; R_Axial_DIN0207_L6.3mm_D2.5mm_P10.16mm_Horizontal
ESP8266_lolin1: NodeMCU1.0(ESP-12E); NodeMCU1.0(12-E)
J1: USB_A; PinHeader_1x02_P2.00mm_Vertical
J8: Conn_01x03_Female; TerminalBlock_4Ucon_1x03_P3.50mm_Vertical
U2: LM324; DIP-14_W7.62mm

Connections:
unnamed: 1K8.1, ESP8266_lolin1.14 (GND), J1.4 (GND), J8.3, U2.11 (V-)
unnamed: 1K8.2, ESP8266_lolin1.26 (D4(GPIO2)), U2.1
unnamed: ESP8266_lolin1.15 (VIN), J1.1 (VBUS), J8.1, U2.4 (V+)
unnamed: ESP8266_lolin1.25 (3.3V), U2.3 (+)
unnamed: J8.2, U2.2 (-)

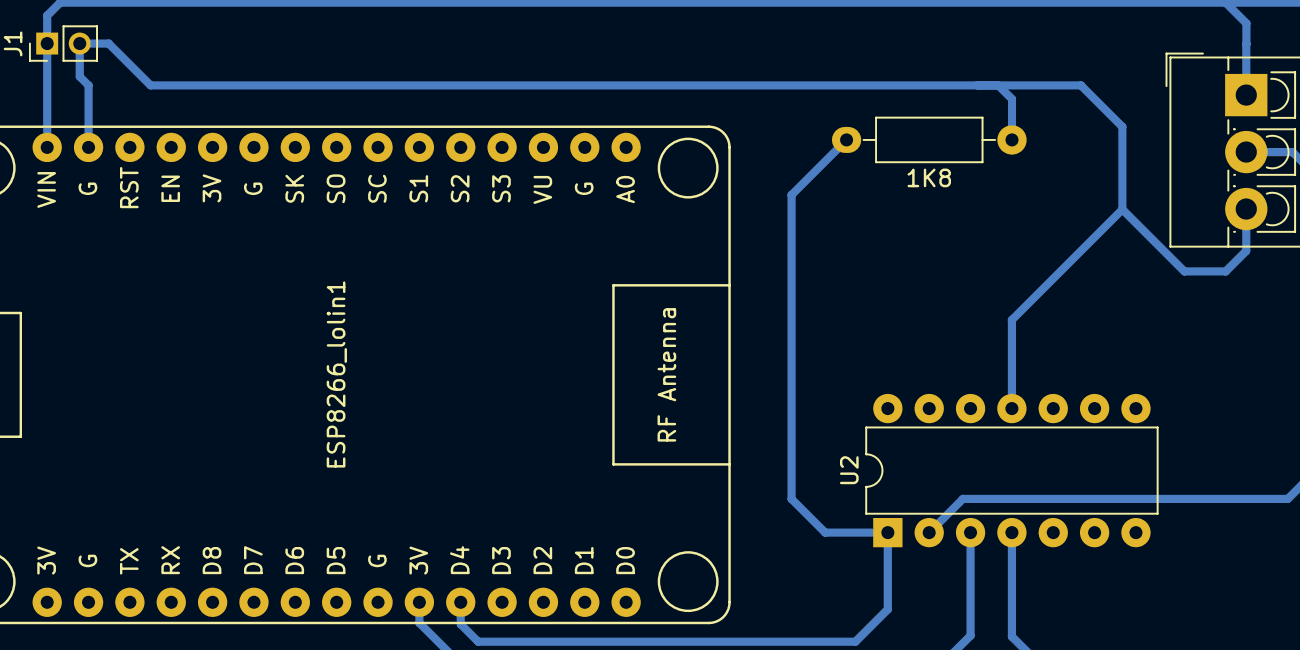
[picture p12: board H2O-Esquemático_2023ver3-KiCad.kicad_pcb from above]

Board: 2 copper layers, 5 parts (0 on the bottom side), 5 nets.

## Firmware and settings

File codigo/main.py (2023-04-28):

from funciones import *       #funciones para hacer el código modular
from wifi import do_connect   #importa función para conexión wifi de wifi.py
import time
#variables para los intentos de conexión
cnt_boot = 0
cont = 0

print ("antes")
#Segundos entre persona para publicar
seg = 10
#Declaración del sensor1
Sensor1 = Conteo(pin=2,seg=seg,k=0.003125,label='Litros 1') 
#con el valor de k=0.002211 da +-0.05L de diferencia, dando un total de 0.5% de error  
#Metodo que publica la constante del sensor
Sensor1.atributo()  
#-------------------------Loop infinito----------------------------------
while True:
  
  try:
   
#publicación de datos en thingsboard
    Sensor1.publica()
    
 #Reinicio de variables
    cnt_boot = 0
    cont = 1

#reintentar conexión en caso de fallo
  except Exception as inst:
    print(inst)
    do_connect(red,clave);
    cnt_boot += 1
    cont += 1
    print("Fail {}".format(cnt_boot))
    if cont >1:
        Sensor1.contador = Sensor1.contador
    if cnt_boot > 10: #si falla la reconexión mas de diez veces se reinicia el dispositivo
      machine.reset()
    time.sleep(1)
  time.sleep(0.1)
#------------------------------------------------------------------------

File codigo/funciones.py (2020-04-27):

from machine import Pin       #libreria para utilizar los GPIO's de la esp
from funcion import *         #importar la función para publicar el thingsboard
from wifi import do_connect   #importa función para conexión wifi de wifi.py
import time


#-------------Datos del dispositivo----------------------#
#Datos de la red de internet
red = 'INFINITUMjpdm'                #Red de internet
clave = '5cbbb04d21'      #contraseña de la red
#red = 'IER'                #Red de internet
#clave = 'acadier2014'      #contraseña de la red

#credenciales del dispositivo configurado en thingsboard
unique_id = 'fd382bc0-49d5-11ea-9ffe-35550336f914'
token = 'Njk5bs2q53mUSXfdvlqc'
#-------------------------------------------------------#


#---------------Clase para el conteo digital del pin-----------------#
class Conteo:
  
#Variables iniciales de la clase
  contador = 0
  T = 0
  data = 0
  constant = 0
  con = 0
  estado_anterior = 0
  contat = 0
  contboot = 0

#Función que inicializa los valores de la clase unicos de cada sensor
  def __init__(self,pin=0,seg=0,k=0,label=''):
    self.inpt = Pin(pin, Pin.IN)
    self.seg = seg
    self.k = k    
    self.label = label
    self.inpt.irq(trigger=Pin.IRQ_RISING, handler=self.my_callback)
   
#Metodo callback que realiza el conteo digital del pin
  def my_callback(self,l):
    self.contador = self.contador +1

#Metodo de constantes del sensor
  def ecuacion(self):
      self.T = (self.contador*self.k)

#Metodo que empaqueta los datos para ser publicados en Thingsboard
  def datos(self):
      self.data  = {self.label: 0}
      self.data[self.label] = self.T 

#Metodo que realiza la publicación de datos por persona
  def publica(self):
    self.ecuacion()
    self.datos()
    if self.inpt.value() != self.estado_anterior:  #entrada ON
        self.con = 0
    else:                          #entrada OFF
        if self.T != 0:                    #si flujo >0
            self.con = self.con +1
            if self.con == self.seg*10:               #si contador = 10
                print("Publicando datos del sensor ",self.label[-1])
                publish_thingsboard(token,unique_id,self.data,'telemetry')
                self.contador = 0
                self.con = 0
    print('sensor ',self.label[-1],' /conteo= ',self.con,' /estado= ',self.inpt.value(),' /consumo= ',self.T)
    self.estado_anterior = self.inpt.value()

#Metodo para publicar la constante del sensor, lo intenta 10 veces
  def atributo(self):
    self.constant  = {self.label[-1]: 0}
    self.constant[self.label[-1]] = self.k 
    while self.contat == 0:
      try:
        publish_thingsboard(token,unique_id,self.constant,'attributes')
        print("Constante Sensor ",self.label[-1])
        self.contat = 1
      except Exception as inst:
        print(inst)
        do_connect(red,clave);
        self.contboot += 1
        print("Fail {}".format(self.contboot))
        if self.contboot > 10: 
          machine.reset()
        time.sleep(1)
      time.sleep(1)
#-------------------------------------------------------------------------#

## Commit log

2020-01-31 Código funcional para la medición de dos sensores con una tarjerta
2020-02-05 Add files via upload
    función modular para ecuaciones del sensor agragada
2020-02-05 funciones modulares de empaquetamiento de datos agregadas
2020-02-05 Reacomodo de código se añade etiquetas para publicar en thingsboard
2020-02-05 Código modular y funcional para 1 sensor
2020-02-06 Se eliminó calculo del flujo, sin volver modular el conteo digital
2020-02-06 Se agrego una clase, aun tiene detalles el código
2020-02-06 Clase para medir volumen de agua
2020-02-07 funcional varios sensores
2020-02-07 Versión 0.6 funcional para 1 o varios sensores
2020-02-10 Explicación de las funciones
2020-02-10 Reacomodo de la clase conteo para simplificar main
2020-02-10 Código modular que publica por persona
2020-02-10 Correción de etiquetas
2020-02-12 Se agrega constante del sensor
2020-02-13 Publicación de constante como atributo
2020-02-13 Optimización de algunas clases
2020-02-14 Comparación de sensor con estado anterior
2020-02-17 Publica constante del sensor
2020-02-18 Optimización de metodos
2020-12-28 agregue un mensaje para MA
2021-01-27 Carpetas completas
    [BASE_CARCASA_H2O.STL, BASE_CARCASA_H2O_CAD.STEP, BASE_MEDIA_H2O.STL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]
2021-01-27 Modifiqué el README
2021-01-27 Borre el swp vacio
2021-01-27 Borre el README de prueba
2021-01-27 Este es el README modelo
2021-01-27 Modifique el README
2021-02-17 modifiqué el nombre
2021-03-08 Update Manual de Montaje.md
2021-03-11 Modifiqué el MO
2021-03-16 Agregué datos de Thingsboard
2021-03-18 Actualicé el Manual de operación
2021-05-21 reduje el c'odigo de main8s y lo pas'e a main.py
2021-06-03 rama principal para 1 sensor de agua
2021-06-16 todo actualizado a 1S
    [BASECARCASAH2O1.STEP, BASECARCASAH2O1.STL, BASEMEDIAH2O1.STEP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]
2023-01-30 Se elimina el divisor de voltaje en esta versión
    [H2O-Esquemático_2023ver1-KiCad.kicad_pcb, H2O-Esquemático_2023ver1-KiCad.kicad_sch, H2O-Esquemático_2023ver2-KiCad.kicad_pcb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]
2023-01-30 Modificación enero 2023
    [H2O-Esquemático_2023ver1-KiCad.kicad_pcb, H2O-Esquemático_2023ver1-KiCad.kicad_sch, H2O-Esquemático_2023ver2-KiCad.kicad_pcb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]
